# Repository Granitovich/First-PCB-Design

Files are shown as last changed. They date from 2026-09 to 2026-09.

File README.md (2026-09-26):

# First PCB Design: STM32G0B1KET6 Custom Board

A custom PCB design built around the **STM32G0B1KET6** microcontroller. This project contains a complete hardware design for a minimal development board featuring power management, debugging interfaces, and a directly mounted TFT display.



## 📌 Features

* **Microcontroller:** STM32G0B1KET6 (ARM Cortex-M0+, 512 KB Flash, 144 KB RAM, up to 64 MHz).
* **Display Interface:** Dedicated pinout and footprint for mounting a TFT LCD module directly on top of the PCB.
* **Power Supply:** 
  * Linear voltage regulator (LDO) to step down input voltage to +3.3V.
  * Decoupling and bulk capacitors for stable operation and MCU noise suppression.
* **Programming & Debugging:** Standard SWD (Serial Wire Debug) header for ST-LINK / J-Link programmers.
* **System Essentials:**
  * Reset circuit with an onboard tactile button and debouncing.
  * Status LEDs for power indication

## 📁 Repository Structure

```text
├── # Schematics, PCB layout files, and KiCad/Altium project source
├── production/        # Production-ready Gerber files, drill files, and pick-and-place (CPL)
├── BOM/               # Bill of Materials (components list with manufacturer part numbers)
└── README.md          # Project documentation

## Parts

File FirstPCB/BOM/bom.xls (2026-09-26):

Comment | Designator | Footprint | JLCPCB Part #
TYPE-C_6P | USB1 | Connector_USB:USB_C_Receptacle_GCT_USB4135-GF-A_6P_TopMnt_Horizontal | C456012
1kOhm | R5 | Resistor_SMD:R_0805_2012Metric | C17513
ENS210-LQFM | IC1 |  | C2991202
4.7kOhm | R1,R6,R7 | Resistor_SMD:R_0805_2012Metric | C17673
4,7uF | C2 | SamacSys_Parts:CAPC2012X140N | C1779
22uF | C3,C6 | CL21A226MQQNNNE:CAPC2012X140N | C45783
100nF | C1,C4,C5 | SamacSys_Parts:CAPC2012X95N | C28233
AMS1117-3.3 | U2 | Package_TO_SOT_SMD:SOT-223-3_TabPin2 | C351784
EVQQ2B03W | S1,S2 | SamacSys_Parts:EVQQ2 | C79178
10kOhm | R4 | Resistor_SMD:R_0805_2012Metric | C17414
Green0805 | LED1 | CRG1206F470R:RESC3115X65N | C2297
STM32G0B1KBT6TR | U1 |  | C7021416
100Ohm | R2,R3 | Resistor_SMD:R_0805_2012Metric | C17408
5.1kOhm | R8,R9 | Resistor_SMD:R_0805_2012Metric | C27834

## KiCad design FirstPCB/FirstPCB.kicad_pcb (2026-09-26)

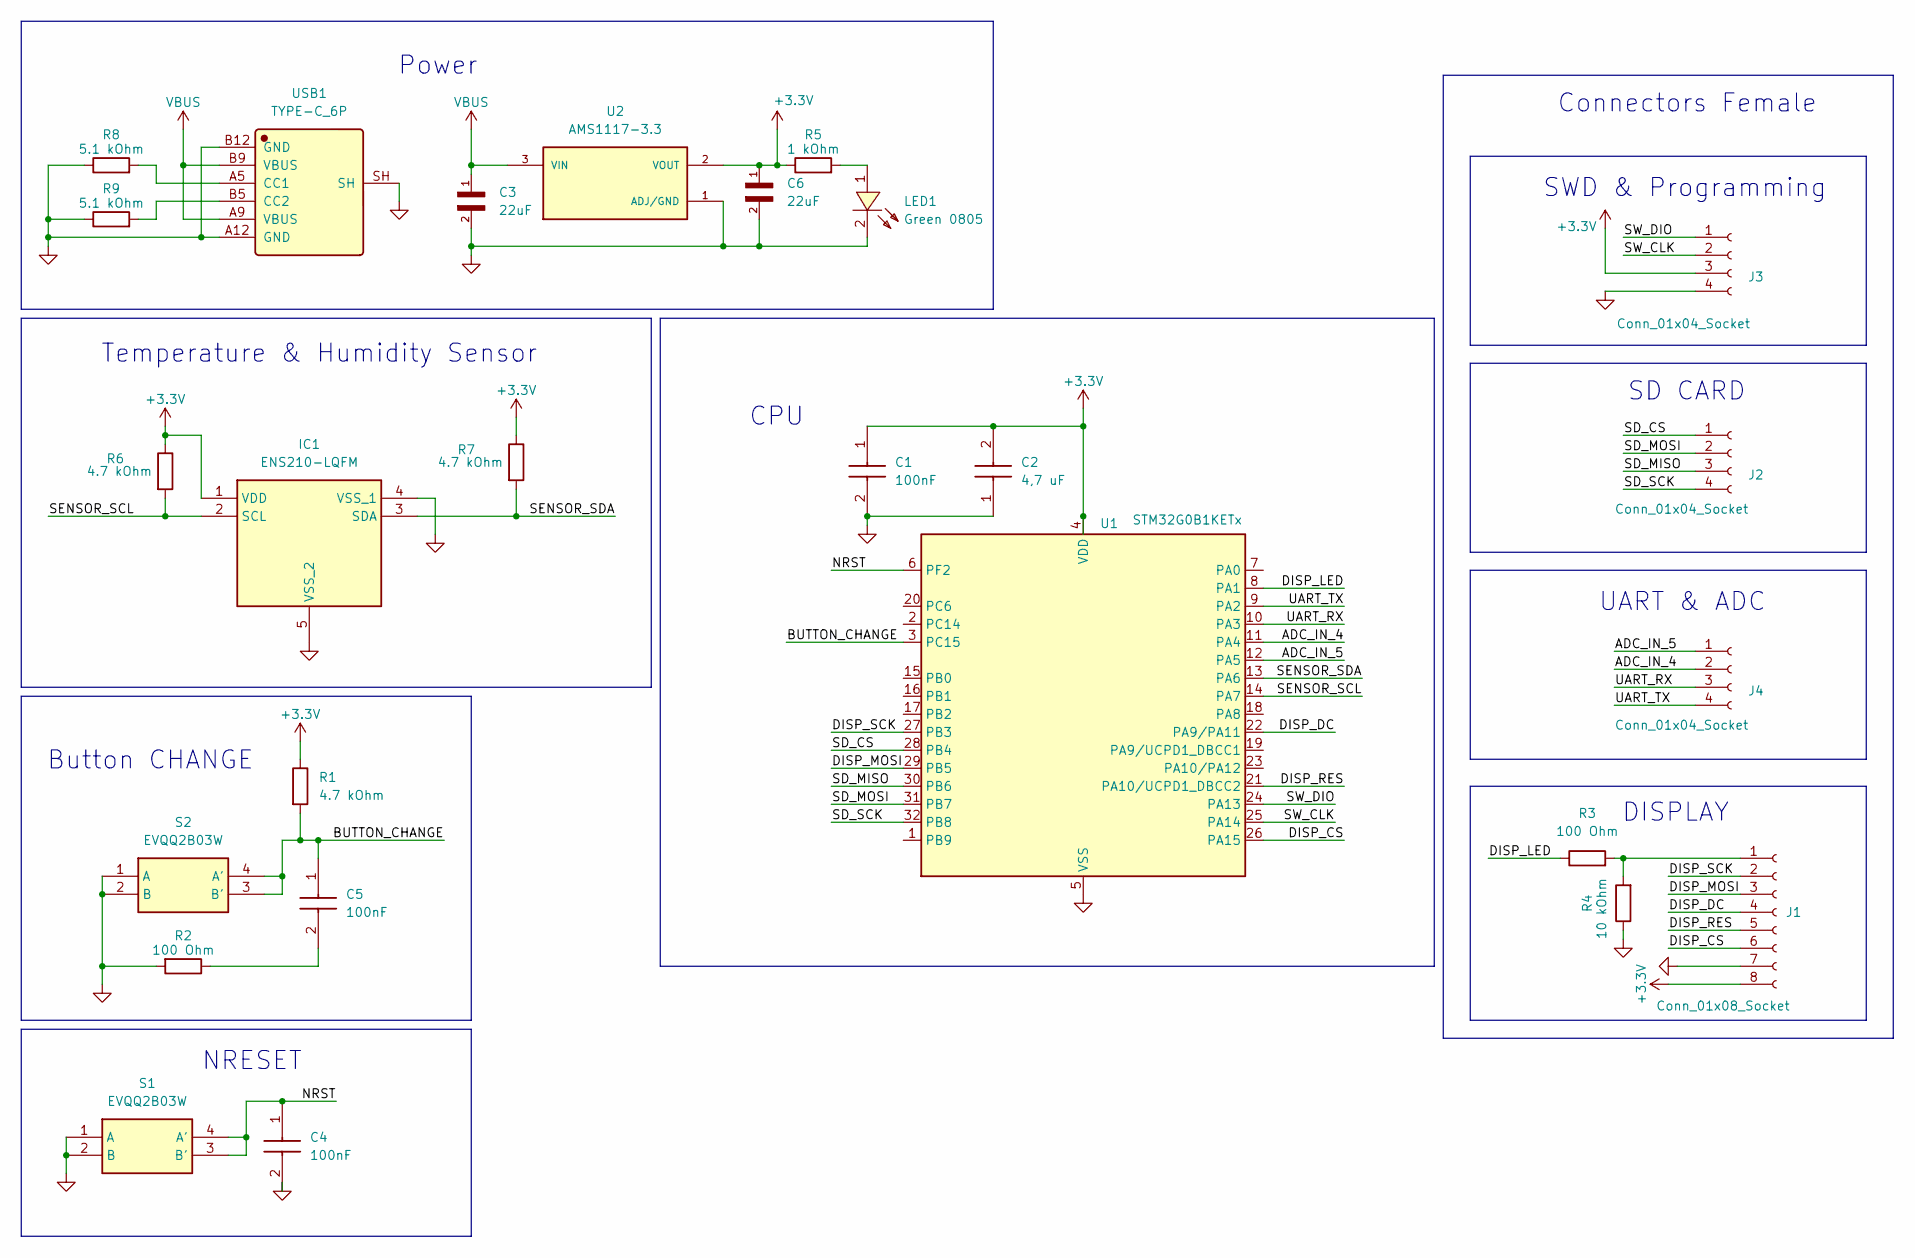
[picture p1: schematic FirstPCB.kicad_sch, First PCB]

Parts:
C1, C4, C5: 100nF; CAPC2012X95N; Manufacturer_Part_Number CL21B104KBCNNNC; Mouser Part Number 187-CL21B104KBCNNNC
C2: 4,7 uF; CAPC2012X140N; Manufacturer_Part_Number CL21A475KAQNNNE; Mouser Part Number 187-CL21A475KAQNNNE
C3, C6: 22uF; CAPC2012X140N
IC1: ENS210-LQFM; SON95P200X200X80-5N; Manufacturer_Part_Number ENS210-LQFM; Mouser Part Number 985-ENS210-LQFM
J1: Conn_01x08_Socket; PinSocket_1x08_P2.54mm_Vertical
J2, J3, J4: Conn_01x04_Socket; PinSocket_1x04_P2.54mm_Vertical
LED1: Green 0805; RESC3115X65N; MPN KT-0805YG; LCSC Part C2292
R1, R6, R7: 4.7 kOhm; R_0805_2012Metric
R2, R3: 100 Ohm; R_0805_2012Metric
R4: 10 kOhm; R_0805_2012Metric
R5: 1 kOhm; R_0805_2012Metric
R8, R9: 5.1 kOhm; R_0805_2012Metric
S1, S2: EVQQ2B03W; EVQQ2; Manufacturer_Part_Number EVQQ2B03W
U1: STM32G0B1KETx; LQFP-32_7x7mm_P0.8mm
U2: AMS1117-3.3; SOT-223-3_TabPin2; PARTREV NA
USB1: TYPE-C_6P; USB_C_Receptacle_GCT_USB4135-GF-A_6P_TopMnt_Horizontal; Manufacturer Part TYPE-C 6P; LCSC C456012

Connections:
+3.3V: C1.1, C2.2, C6.1, IC1.1 (VDD), J1.8, J3.3, R1.1, R5.1, R6.1, R7.1, U1.4 (VDD), U2.2 (VOUT)
/ADC_IN_4: J4.2, U1.11 (PA4)
/ADC_IN_5: J4.1, U1.12 (PA5)
/BUTTON_CHANGE: C5.1, R1.2, S2.3 (B'), S2.4 (A'), U1.3 (PC15)
/DISP_CS: J1.6, U1.26 (PA15)
/DISP_DC: J1.4, U1.22 (PA9/PA11)
/DISP_LED: R3.1, U1.8 (PA1)
/DISP_MOSI: J1.3, U1.29 (PB5)
/DISP_RES: J1.5, U1.21 (PA10/UCPD1_DBCC2)
/DISP_SCK: J1.2, U1.27 (PB3)
/NRST: C4.1, S1.3 (B'), S1.4 (A'), U1.6 (PF2)
/SD_CS: J2.1, U1.28 (PB4)
/SD_MISO: J2.3, U1.30 (PB6)
/SD_MOSI: J2.2, U1.31 (PB7)
/SD_SCK: J2.4, U1.32 (PB8)
/SENSOR_SCL: IC1.2 (SCL), R6.2, U1.14 (PA7)
/SENSOR_SDA: IC1.3 (SDA), R7.2, U1.13 (PA6)
/SW_CLK: J3.2, U1.25 (PA14)
/SW_DIO: J3.1, U1.24 (PA13)
/UART_RX: J4.3, U1.10 (PA3)
/UART_TX: J4.4, U1.9 (PA2)
GND: C1.2, C2.1, C3.2, C4.2, C6.2, IC1.4 (VSS_1), IC1.5 (VSS_2), J1.7, J3.4, LED1.2, R2.2, R4.1, R8.1, R9.1, S1.1 (A), S1.2 (B), S2.1 (A), S2.2 (B), U1.5 (VSS), U2.1 (ADJ/GND), USB1.A12 (GND), USB1.B12 (GND), USB1.SH
unnamed: C5.2, R2.1
unnamed: J1.1, R3.2, R4.2
unnamed: LED1.1, R5.2
unnamed: R8.2, USB1.A5 (CC1)
unnamed: R9.2, USB1.B5 (CC2)
VBUS: C3.1, U2.3 (VIN), USB1.A9 (VBUS), USB1.B9 (VBUS)

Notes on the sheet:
Temperature & Humidity Sensor
Button CHANGE
CPU
Connectors Female
DISPLAY
SD CARD
NRESET
UART & ADC
SWD & Programming
Power

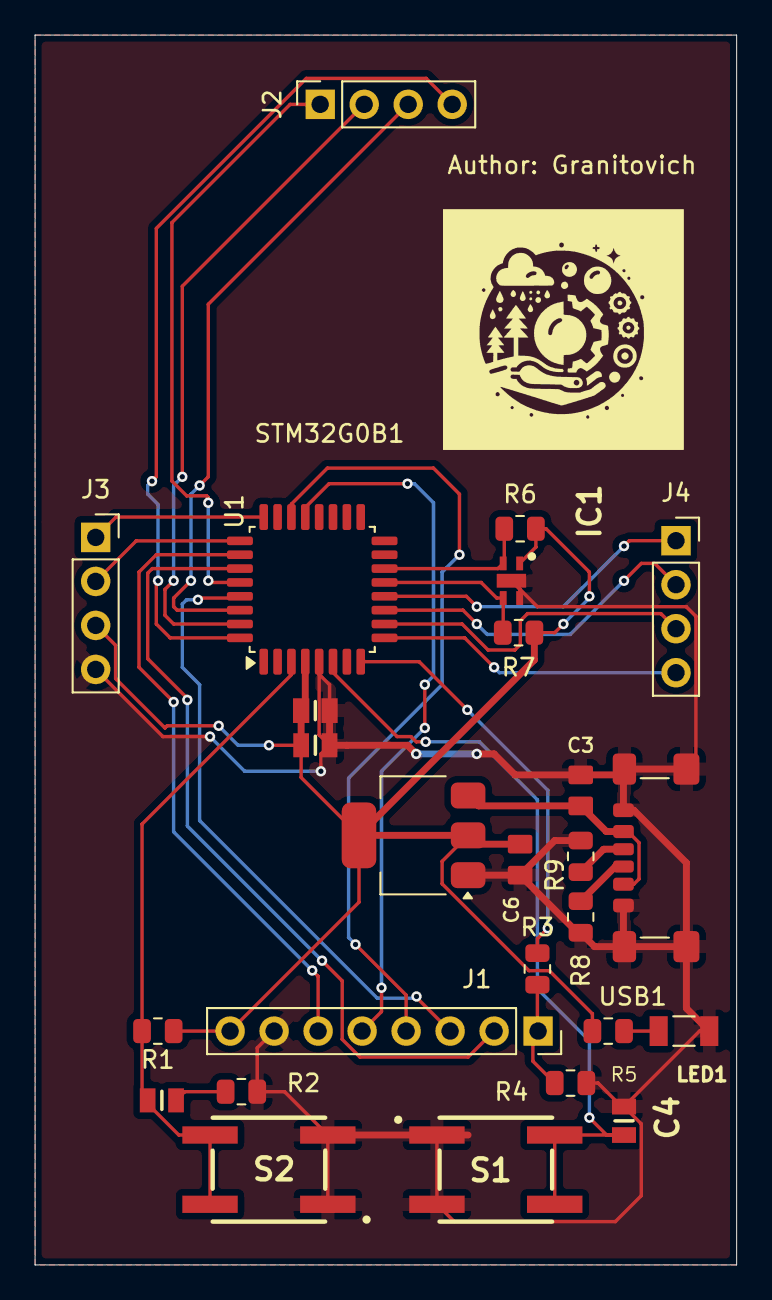
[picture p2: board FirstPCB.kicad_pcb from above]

Board: 2 copper layers, 40.5 x 71.0 mm, 26 parts (0 on the bottom side), 28 nets.

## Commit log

2026-09-21 Basic package
    [FirstPCB.kicad_pcb, FirstPCB.kicad_sch]
2026-09-21 added Voltage Regulator
    [FirstPCB.kicad_pcb, FirstPCB.kicad_sch]
2026-09-21 added sensor and schematic update
    [FirstPCB.kicad_pcb, FirstPCB.kicad_sch]
2026-09-22 shematic finished
    [FirstPCB.kicad_pcb, FirstPCB.kicad_sch]
2026-09-22 before routing
    [FirstPCB.kicad_pcb, FirstPCB.kicad_sch]
2026-09-22 minimal routing
    [FirstPCB.kicad_pcb]
2026-09-22 finished routing
    [FirstPCB.kicad_pcb]
2026-09-23 update gerber
    [FirstPCB-B_Cu.gbr, FirstPCB-B_Mask.gbr, FirstPCB-B_Paste.gbr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]
2026-09-26 design finished, ordered pcb
    [FirstPCB-B_Cu.gbr, FirstPCB-B_Mask.gbr, FirstPCB-B_Paste.gbr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]
2026-09-26 Add project description to README
    The project includes all the files needed to build a minimal board with a microcontroller and a single TFT display mounted on top.
2026-09-26 Revise README for STM32G0B1KET6 project
    Expanded project description and added features, repository structure, and formatting.
2026-09-26 Replace image in README.md
    Updated image in README for the STM32G0B1KET6 custom board.
2026-09-26 model updated
    [FirstPCB.kicad_pcb]
2026-10-12 Fix Resistor
2026-11-03 fixed button
2026-11-03 update pcb
